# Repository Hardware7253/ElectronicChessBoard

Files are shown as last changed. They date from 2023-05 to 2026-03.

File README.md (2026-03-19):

# Electronic Chess Board
Welcome to the Electronic Chess Board project repository. This project combines an electronic chess board with a chess engine, offering a more tactile way to train against an AI opponent.

board

## Overview
The project's core objective is to deliver an interactive chess experience, allowing users to engage in matches against an AI opponent.
This AI opponent employs a minimax algorithm for strategic decision-making, with a variable search depth of 3 to 6 based on time availability. 
The chess board integrates 64 hall effect sensors to precisely detect piece positions, while the AI's moves are visually indicated using 64 LEDs.

## Code
In the [Code](/Code) directory, you'll find the firmware that powers the project. This firmware includes the chess engine responsible for AI decision-making.
The project is programmed in embedded rust, and is designed to run on the custom STM32F103C8T6 chess board.

## CAD
The [CAD](/Cad) directory contains KiCad schematics for the custom chess board PCB. Additionally, you'll find laser cutting files and 3D design files for the casing of the electronic chess board.
Manufacturing outputs for the PCB can be found in the [Manufacture](/Cad/ChessBoardKiCad/Manufacture) directory.

# Manual

## Starting the game
To begin playing, the game board will prompt you to select your team—black or white. Simply press the button while your desired team is displayed on the screen.

## Setting up the board
After starting the game, you'll be prompted to set up the chessboard. Arrange the 32 chess pieces in their starting positions, with the color that represents your team closest to you. For instance, if you are playing as the black team, ensure that the black pieces are positioned on the bottom of the board closest to you. If you need assistance during this process, you can hold down the button at any time. Doing so will illuminate LEDs on the board, indicating missing pieces or incorrectly placed ones. Once all pieces are correctly positioned, the game will automatically commence.

## Playing the game
The game follows a turn-based structure with both the user and the chess engine taking their respective turns. To make a move, simply move a chess piece and press the button to confirm that you have completed your turn. When it's the computer's turn to move, it will signal its move by blinking LEDs to indicate the destination square.

## Capturing
When capturing an opponent's piece, start by removing the captured piece from the board. Then, move your piece to its final destination and press the button to signal the end of your turn. This behavior is consistent with en passant moves, where you must first remove the captured pawn from the board before completing your move.

## Castling
To execute a castling move, move your king to its castled position without moving the rook. Press the button to indicate that you have finished your turn. After this, you may move your rook to the opposite side of the king to complete the castling maneuver.

## Errors
Errors are most likely to occur when an illegal move is made. The board's LEDs will illuminate to highlight the pieces that need adjustment to rectify the error. Additionally, the LCD screen will prompt you to revert the piece positions.

Errors may also happen when pieces are moved during the chess engine's turn. In such cases, you may notice multiple LEDs being lit up, some indicating the engine's move and others indicating pieces in the wrong position. This typically occurs when one or more pieces are slightly off-center on their squares. To resolve this issue, simply adjust the misaligned pieces inward slightly to correct the error.

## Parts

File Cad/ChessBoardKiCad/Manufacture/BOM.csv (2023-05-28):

Comment | Designator | Footprint | JLCPCB Part #
10u | C1 | Capacitor_SMD:C_0603_1608Metric | C96446
100n | C2, C3, C4, C5, C11, C14, C15, C16, C17, C18, C19, C20, C21, C22, C23, C24, C25, C26, C27, C28, C29, C30, C31, C32, C33, C34, C35, C36, C37, C38, C39, C40, C41, C42, C43, C44, C45, C46, C47, C48, C49, C50, C51, C52, C53, C54, C55, C56, C57, C58, C59, C60, C61, C62, C63, C64, C65, C66, C67, C68, C69, C70, C71, C72, C73, C74, C75, C76, C77 | Capacitor_SMD:C_0402_1005Metric | C1525
10n | C6 | Capacitor_SMD:C_0402_1005Metric | C15195
1u | C7, C8 | Capacitor_SMD:C_0402_1005Metric | C52923
22u | C9, C10 | Capacitor_SMD:C_0805_2012Metric | C45783
14p | C12, C13 | Capacitor_SMD:C_0402_1005Metric | C1548
RED | D1, D2, D3, D4, D5, D6, D7, D8, D9, D10, D11, D12, D13, D14, D15, D16, D17, D18, D19, D20, D21, D22, D23, D24, D25, D26, D27, D28, D29, D30, D31, D32, D33, D34, D35, D36, D37, D38, D39, D40, D41, D42, D43, D44, D45, D46, D47, D48, D49, D50, D51, D52, D53, D54, D55, D56, D57, D58, D59, D60, D61, D62, D63, D64, D65 | LED_SMD:LED_0603_1608Metric | C72041
WC1602A | DS1 | Display:WC1602A
120R | FB1 | Inductor_SMD:L_0603_1608Metric | C96702
MountingHole | H1, H2, H3, H4 | MountingHole:MountingHole_3.2mm_M3
USB_C_Receptacle | J1 | USB-C:USB-310D-B-SU | C309349
Conn_01x04_Pin | J2 | Connector_PinHeader_2.54mm:PinHeader_1x04_P2.54mm_Vertical
SolderJumper_2_Open | JP1 | Jumper:SolderJumper-2_P1.3mm_Open_Pad1.0x1.5mm
S9013 | Q1, Q2, Q3, Q4, Q5, Q6, Q7, Q8 | Package_TO_SOT_SMD:SOT-23 | C8512
1k5 | R1, R6, R31, R41, R51, R53, R63, R73, R83, R85 | Resistor_SMD:R_0402_1005Metric | C25867
10k | R2, R3, R32, R42, R52, R62, R72, R82, R84, R86 | Resistor_SMD:R_0402_1005Metric | C25744
5k1 | R4, R5 | Resistor_SMD:R_0402_1005Metric | C25905
2k7 | R7, R8, R9, R10, R11, R12, R13, R14, R15, R16, R17, R18, R19, R20, R21, R22, R23, R24, R25, R26, R27, R28, R29, R30, R33, R34, R35, R36, R37, R38, R39, R40, R43, R44, R45, R46, R47, R48, R49, R50, R54, R55, R56, R57, R58, R59, R60, R61, R64, R65, R66, R67, R68, R69, R70, R71, R74, R75, R76, R77, R78, R79, R80, R81 | Resistor_SMD:R_0402_1005Metric | C100347
10k | RV1 | Potentiometer_SMD:Potentiometer_Bourns_TC33X_Vertical | C515300
SW_SPST | SW1 | Button_Switch_Keyboard:SW_Cherry_MX_1.00u_PCB
AMS1117-3.3 | U1 | Package_TO_SOT_SMD:SOT-223-3_TabPin2 | C6186
STM32F103C8T6 | U2 | Package_QFP:LQFP-48_7x7mm_P0.5mm | C8734
USBLC6-2SC6 | U3 | Package_TO_SOT_SMD:SOT-23-6 | C111212
74HC595 | U4, U5, U6 | Package_SO:SOIC-16_3.9x9.9mm_P1.27mm | C5947
UHE4913G-AE3-R | U7, U8, U9, U10, U11, U12, U13, U14, U15, U16, U17, U18, U19, U20, U21, U22, U23, U24, U25, U26, U27, U28, U29, U30, U31, U32, U33, U34, U35, U36, U37, U38, U39, U40, U41, U42, U43, U44, U45, U46, U48, U49, U50, U51, U52, U53, U54, U55, U56, U57, U58, U59, U60, U61, U62, U63, U65, U66, U67, U68, U69, U70, U71, U72 | Package_TO_SOT_SMD:SOT-23W | C86815
CD4051BM | U47, U64, U73, U74, U75, U76, U77, U78, U79, U80, U81 | Package_SO:SOIC-16_3.9x9.9mm_P1.27mm | C21379
8Mhz | Y1 | Crystal:Crystal_SMD_3225-4Pin_3.2x2.5mm | C403948

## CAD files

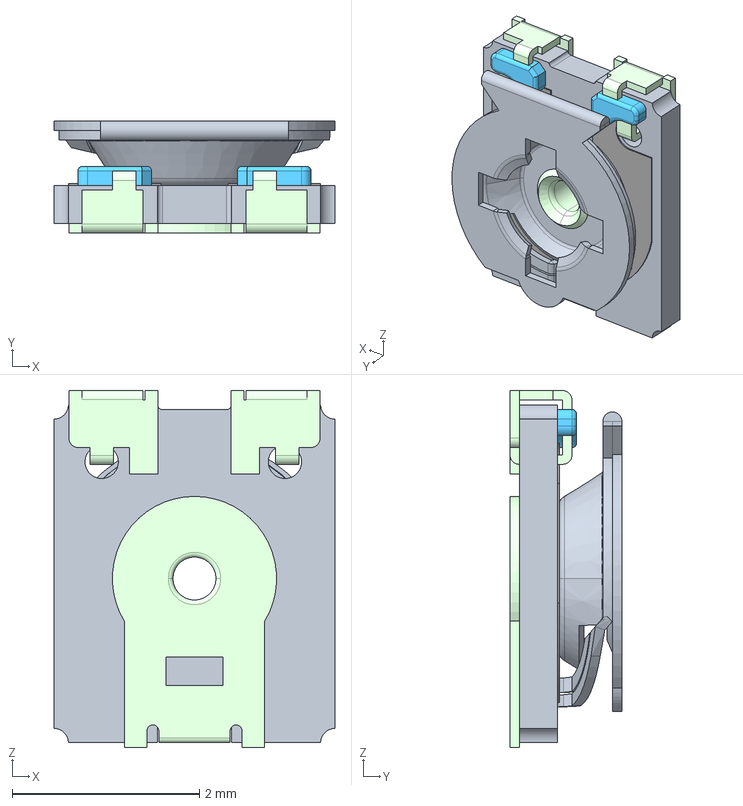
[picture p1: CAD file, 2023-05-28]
Cad/ChessBoardKiCad/3D/TC33X-1-103E.stp
3.00 x 1.19 x 3.81 mm
TC33X_SUBSTRATE
TC33X_ELEMENT
TC33X-1_COLLECTOR
TC33X_CONTACT
TC33X_TERMINALS
TC33X_SOLDER

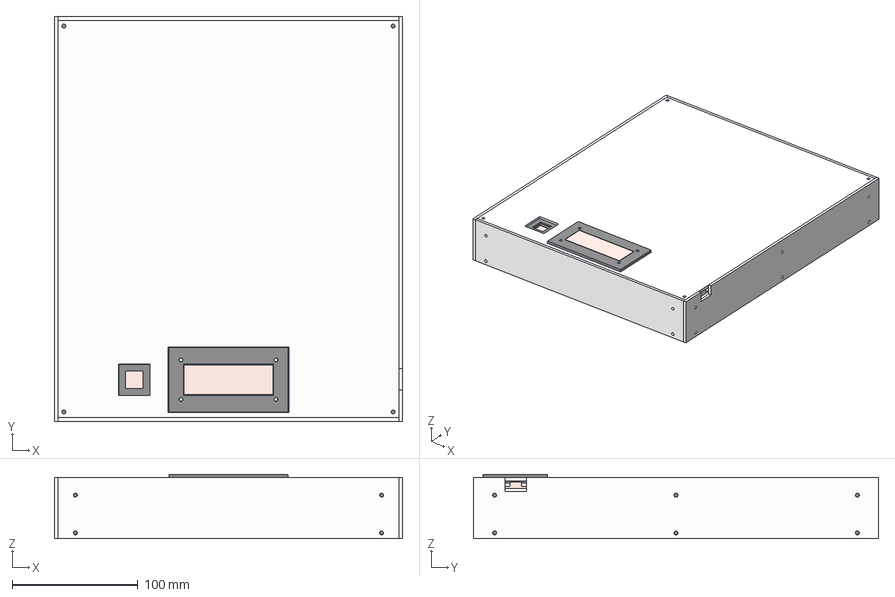
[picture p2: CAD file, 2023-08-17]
Cad/Design Files/Case.step
277.2 x 322.2 x 51.0 mm
PCB
Corner x 6
Washer x 4
PlateWasher x 4
Hardware
Panel1 x 2
Panel2
Panel3
TopPanel
Brace
SwitchPlate
ScreenCover

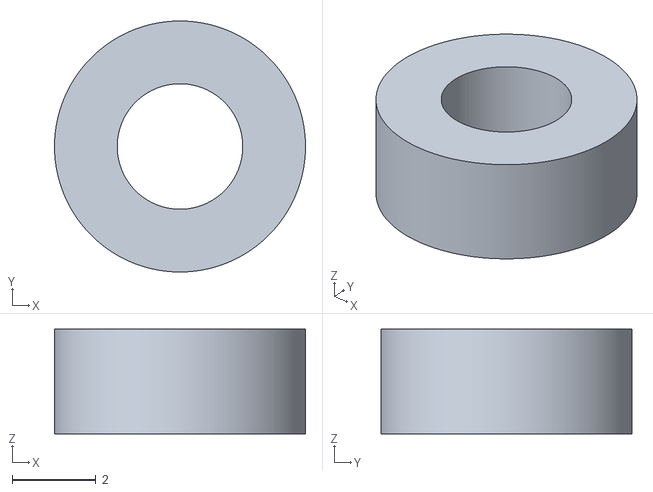
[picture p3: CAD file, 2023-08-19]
Cad/Manufacturing/ScreenSpacer.stl
6.00 x 6.00 x 2.50

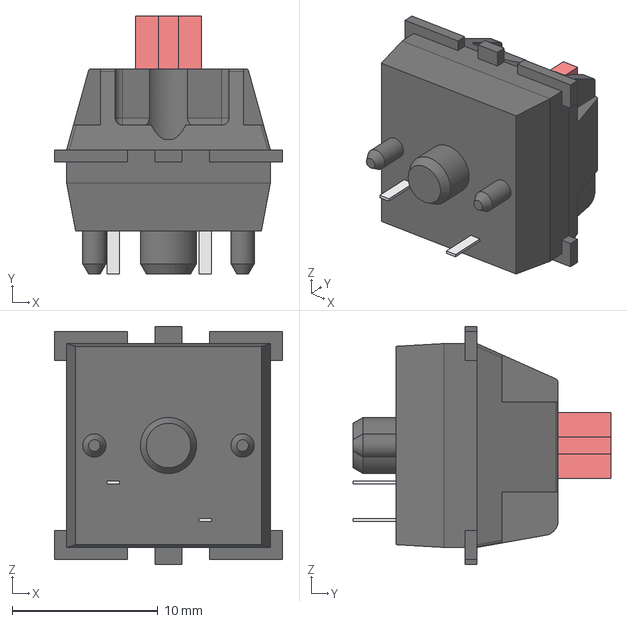
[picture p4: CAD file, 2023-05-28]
Cad/ChessBoardKiCad/3D/cherry-mx_switch.step
15.6 x 17.7 x 16.3 mm

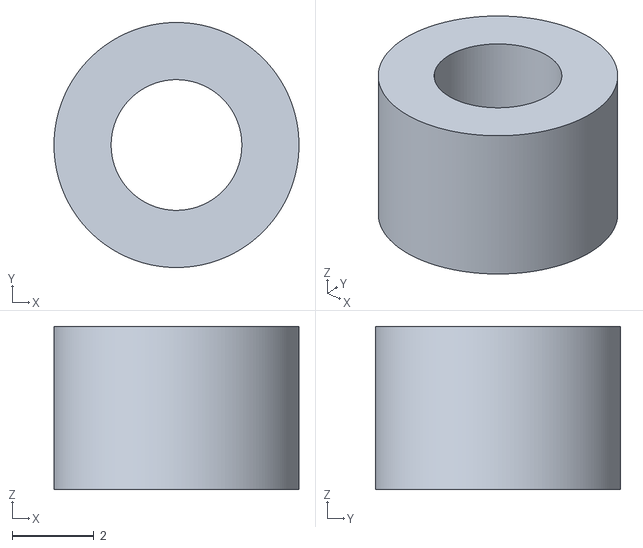
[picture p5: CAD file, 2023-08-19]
Cad/Manufacturing/PlateSpacer.stl
6.00 x 6.00 x 4.00

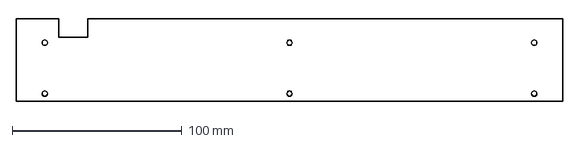
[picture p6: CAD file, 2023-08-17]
Cad/Manufacturing/LongPanelCutout.dxf
322.2 x 48.6 mm

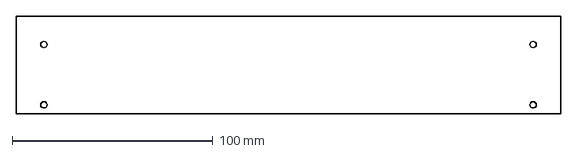
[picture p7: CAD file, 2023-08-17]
Cad/Manufacturing/ShortPanel.dxf
271.2 x 48.6 mm

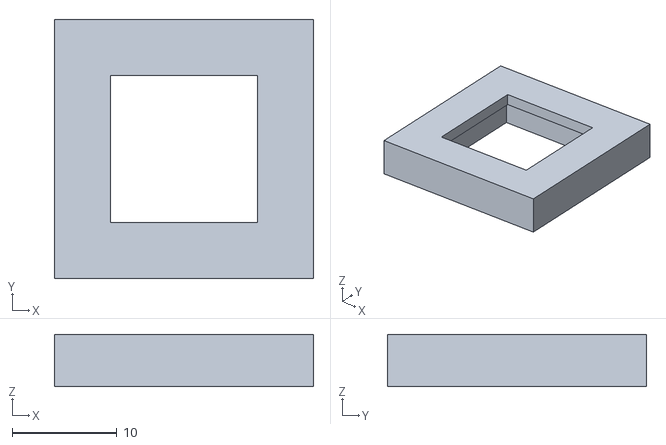
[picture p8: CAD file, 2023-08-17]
Cad/Manufacturing/SwitchPlate.stl
24.7 x 24.7 x 5.00

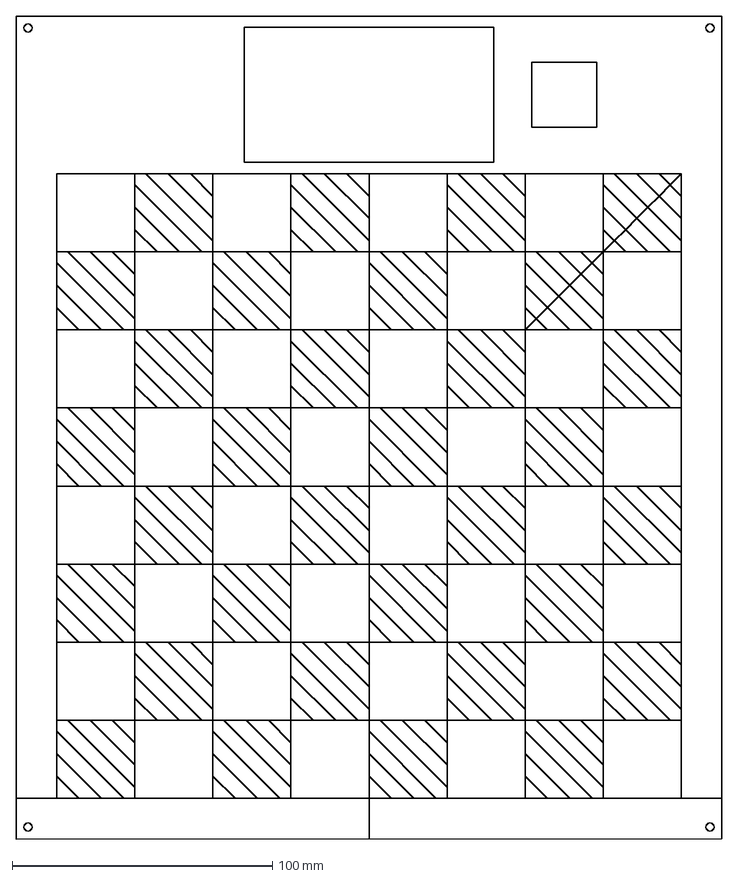
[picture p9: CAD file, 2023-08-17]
Cad/Manufacturing/TopPanel.dxf
271.2 x 316.2 mm

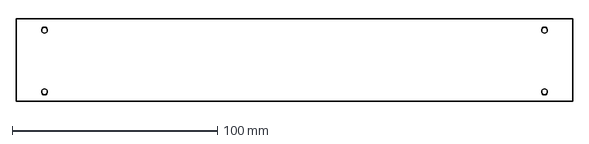
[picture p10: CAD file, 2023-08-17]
Cad/Manufacturing/Brace.dxf
271.2 x 40.0 mm

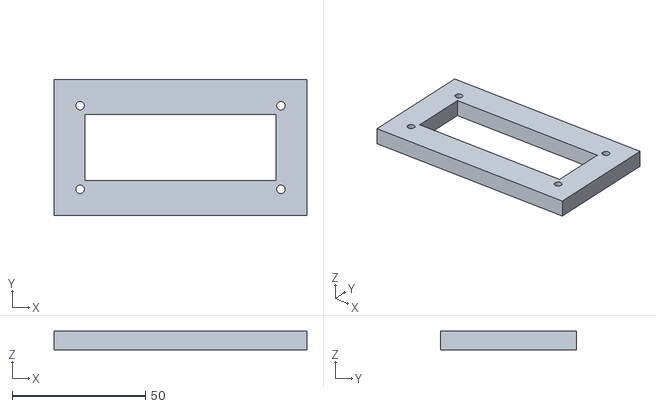
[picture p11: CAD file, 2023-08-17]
Cad/Manufacturing/ScreenCover.stl
95.0 x 51.0 x 7.00

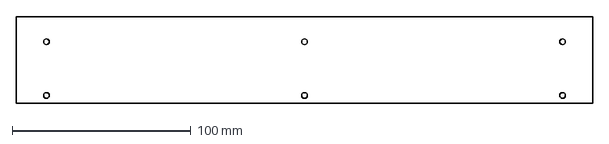
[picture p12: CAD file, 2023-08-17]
Cad/Manufacturing/LongPanel.dxf
322.2 x 48.6 mm

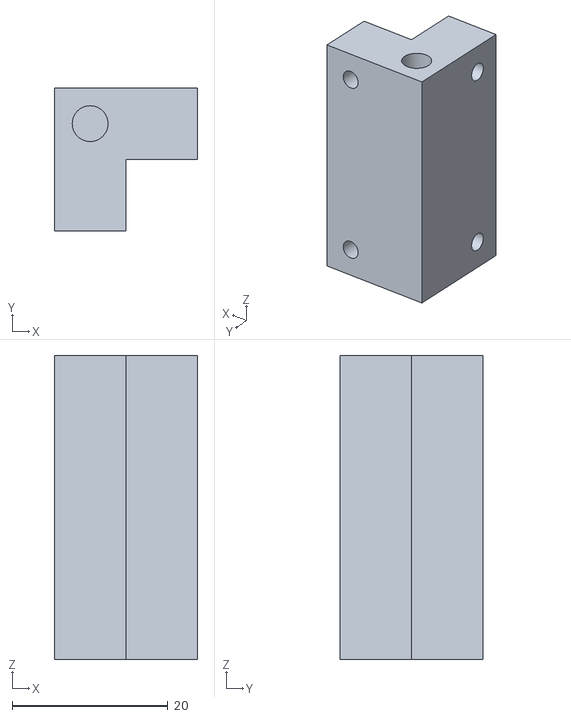
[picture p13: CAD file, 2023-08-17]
Cad/Manufacturing/Corner.stl
18.4 x 18.4 x 39.0

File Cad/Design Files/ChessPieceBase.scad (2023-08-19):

 $fa = 1;
 $fs = 0.1;
 
 // Chess magnet holder pieces
 // These pieces are glued to the bottom of normal chess pieces
 //  Recommended to be printed with a clear filament to diffuse the LED light from the PCB
 
piece_base_diameter = 20; // Diameter of the chess piece

magnet_diameter = 12; // Diameter of the magnet
magnet_height = 1; // Height of the magnet

height_from_board = 5; // Total distance to raise the attached piece from the board

difference() {
    
    // Main base piece cylinder
    cylinder( height_from_board, piece_base_diameter / 2,  piece_base_diameter / 2, false);
    
    // Magnet pocket cut cylinder
    translate([0, 0, height_from_board - magnet_height])
        cylinder(magnet_height + 0.01 , (magnet_diameter / 2), magnet_diameter / 2, false);
}
 

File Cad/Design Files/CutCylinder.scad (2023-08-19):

 $fa = 1;
 $fs = 0.1;
 
 height = 2.5; // Height of the cylinder
 internal_cylinder = 3; // Diameter of the internal cylinder (cavity)
 external_cylinder = 6; // Diamter of the external cyclinder
 
 difference() {
    cylinder( height, external_cylinder / 2, external_cylinder / 2, true);
    cylinder( height + 1, internal_cylinder / 2, internal_cylinder / 2, true);
 }
 
 

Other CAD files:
Cad/Design Files/Case.f3d

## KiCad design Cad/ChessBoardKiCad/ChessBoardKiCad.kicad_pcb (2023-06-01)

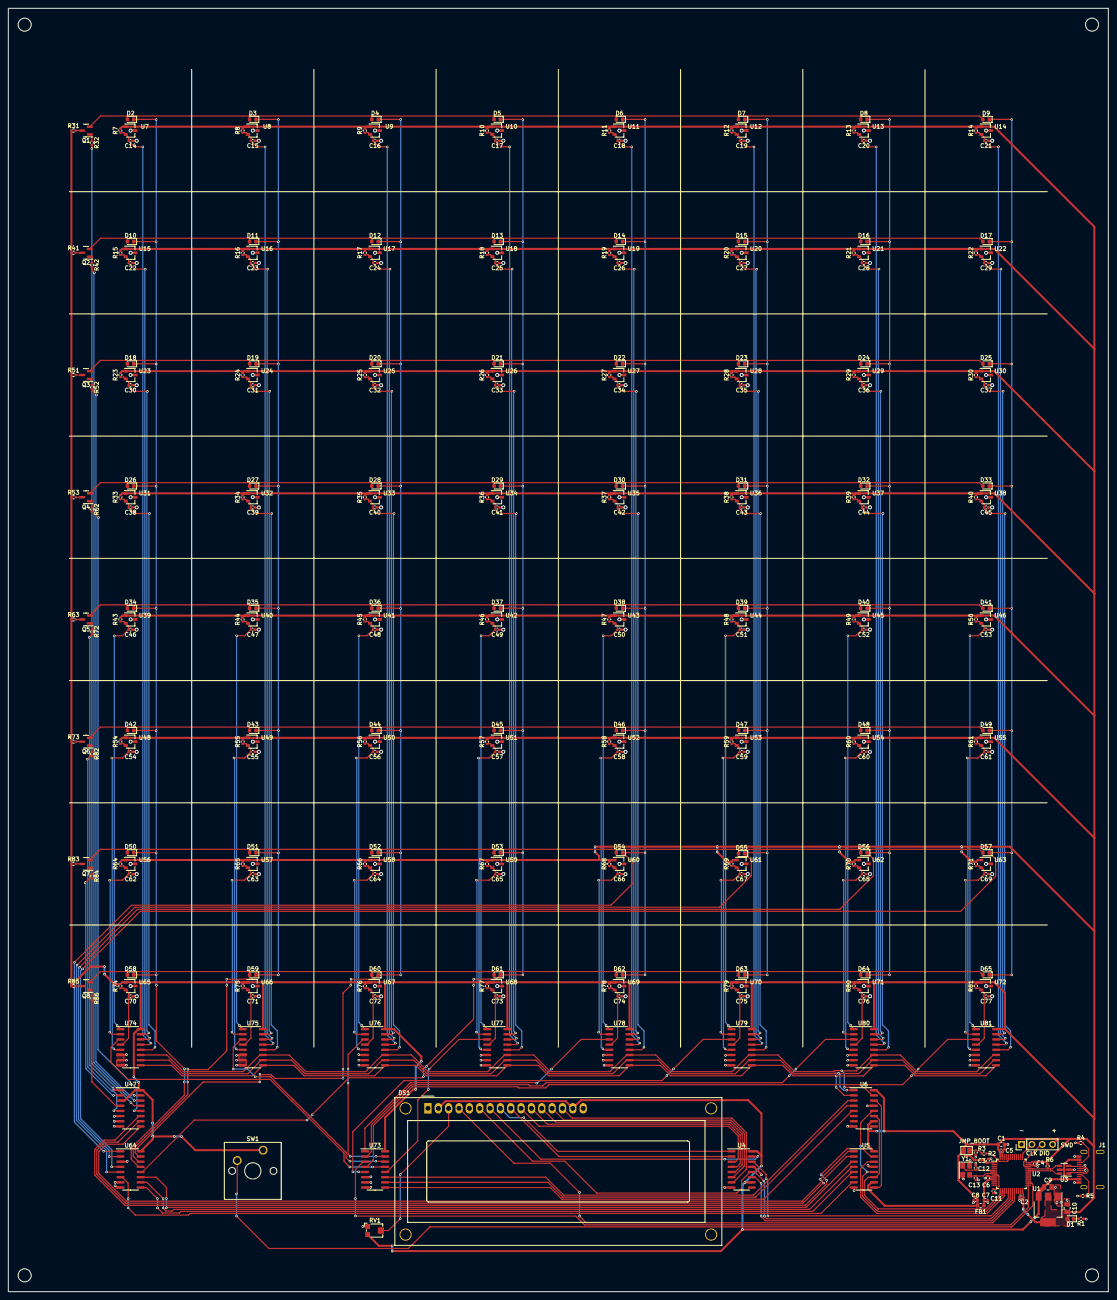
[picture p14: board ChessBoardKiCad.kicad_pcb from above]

Board: 2 copper layers, 270.0 x 315.0 mm, 329 parts (0 on the bottom side), 162 nets.

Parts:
C1: 10u; C_0603_1608Metric
C2, C3, C4, C5, C11, C14, C15, C16, C17, C18, C19, C20, C21, C22, C23, C24, C25, C26, C27, C28, C29, C30, C31, C32, C33, C34, C35, C36, C37, C38, C39, C40, C41, C42, C43, C44, C45, C46, C47, C48, C49, C50, C51, C52, C53, C54, C55, C56, C57, C58, C59, C60, C61, C62, C63, C64, C65, C66, C67, C68, C69, C70, C71, C72, C73, C74, C75, C76, C77: 100n; C_0402_1005Metric
C6: 10n; C_0402_1005Metric
C7, C8: 1u; C_0402_1005Metric
C9, C10: 22u; C_0805_2012Metric
C12, C13: 14p; C_0402_1005Metric
D1, D2, D3, D4, D5, D6, D7, D8, D9, D10, D11, D12, D13, D14, D15, D16, D17, D18, D19, D20, D21, D22, D23, D24, D25, D26, D27, D28, D29, D30, D31, D32, D33, D34, D35, D36, D37, D38, D39, D40, D41, D42, D43, D44, D45, D46, D47, D48, D49, D50, D51, D52, D53, D54, D55, D56, D57, D58, D59, D60, D61, D62, D63, D64, D65: RED; LED_0603_1608Metric
DS1: WC1602A
FB1: 120R; L_0603_1608Metric
H1, H2, H3, H4: MountingHole; MountingHole_3.2mm_M3
J1: USB_C_Receptacle; USB-310D-B-SU
J2: Conn_01x04_Pin; PinHeader_1x04_P2.54mm_Vertical
JP1: SolderJumper_2_Open; SolderJumper-2_P1.3mm_Open_Pad1.0x1.5mm
Q1, Q2, Q3, Q4, Q5, Q6, Q7, Q8: S9013; SOT-23
R1, R6, R31, R41, R51, R53, R63, R73, R83, R85: 1k5; R_0402_1005Metric
R2, R3, R32, R42, R52, R62, R72, R82, R84, R86: 10k; R_0402_1005Metric
R4, R5: 5k1; R_0402_1005Metric
R7, R8, R9, R10, R11, R12, R13, R14, R15, R16, R17, R18, R19, R20, R21, R22, R23, R24, R25, R26, R27, R28, R29, R30, R33, R34, R35, R36, R37, R38, R39, R40, R43, R44, R45, R46, R47, R48, R49, R50, R54, R55, R56, R57, R58, R59, R60, R61, R64, R65, R66, R67, R68, R69, R70, R71, R74, R75, R76, R77, R78, R79, R80, R81: 2k7; R_0402_1005Metric
RV1: 10k; Potentiometer_Bourns_TC33X_Vertical
SW1: SW_SPST; SW_Cherry_MX_1.00u_PCB
U1: AMS1117-3.3; SOT-223-3_TabPin2
U2: STM32F103C8T6; LQFP-48_7x7mm_P0.5mm
U3: USBLC6-2SC6; SOT-23-6
U4, U5, U6: 74HC595; SOIC-16_3.9x9.9mm_P1.27mm
U7, U8, U9, U10, U11, U12, U13, U14, U15, U16, U17, U18, U19, U20, U21, U22, U23, U24, U25, U26, U27, U28, U29, U30, U31, U32, U33, U34, U35, U36, U37, U38, U39, U40, U41, U42, U43, U44, U45, U46, U48, U49, U50, U51, U52, U53, U54, U55, U56, U57, U58, U59, U60, U61, U62, U63, U65, U66, U67, U68, U69, U70, U71, U72: UHE4913G-AE3-R; SOT-23W
U47, U64, U73, U74, U75, U76, U77, U78, U79, U80, U81: CD4051BM; SOIC-16_3.9x9.9mm_P1.27mm
Y1: 8Mhz; Crystal_SMD_3225-4Pin_3.2x2.5mm

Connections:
+3.3V: C1.1, C2.1, C3.1, C4.1, C5.1, C8.1, C10.1, D1.2 (A), FB1.2, J2.4, JP1.1 (A), R6.2, R7.1, R8.1, R9.1, R10.1, R11.1, R12.1, R13.1, R14.1, R15.1, R16.1, R17.1, R18.1, R19.1, R20.1, R21.1, R22.1, R23.1, R24.1, R25.1, R26.1, R27.1, R28.1, R29.1, R30.1, R31.1, R33.1, R34.1, R35.1, R36.1, R37.1, R38.1, R39.1, R40.1, R41.1, R43.1, R44.1, R45.1, R46.1, R47.1, R48.1, R49.1, R50.1, R51.1, R53.1, R54.1, R55.1, R56.1, R57.1, R58.1, R59.1, R60.1, R61.1, R63.1, R64.1, R65.1, R66.1, R67.1, R68.1, R69.1, R70.1, R71.1, R73.1, R74.1, R75.1, R76.1, R77.1, R78.1, R79.1, R80.1, R81.1, R83.1, R85.1, SW1.1 (A), U1.2 (VO), U2.1 (VBAT), U2.24 (VDD), U2.36 (VDD), U2.48 (VDD), U5.10 (~SRCLR), U5.16 (VCC), U6.10 (~SRCLR), U6.16 (VCC), U7.1 (VCC), U8.1 (VCC), U9.1 (VCC), U10.1 (VCC), U11.1 (VCC), U12.1 (VCC), U13.1 (VCC), U14.1 (VCC), U15.1 (VCC), U16.1 (VCC), U17.1 (VCC), U18.1 (VCC), U19.1 (VCC), U20.1 (VCC), U21.1 (VCC), U22.1 (VCC), U23.1 (VCC), U24.1 (VCC), U25.1 (VCC), U26.1 (VCC), U27.1 (VCC), U28.1 (VCC), U29.1 (VCC), U30.1 (VCC), U31.1 (VCC), U32.1 (VCC), U33.1 (VCC), U34.1 (VCC), U35.1 (VCC), U36.1 (VCC), U37.1 (VCC), U38.1 (VCC), U39.1 (VCC), U40.1 (VCC), U41.1 (VCC), U42.1 (VCC), U43.1 (VCC), U44.1 (VCC), U45.1 (VCC), U46.1 (VCC), U47.3 (X), U47.16 (VDD), U48.1 (VCC), U49.1 (VCC), U50.1 (VCC), U51.1 (VCC), U52.1 (VCC), U53.1 (VCC), U54.1 (VCC), U55.1 (VCC), U56.1 (VCC), U57.1 (VCC), U58.1 (VCC), U59.1 (VCC), U60.1 (VCC), U61.1 (VCC), U62.1 (VCC), U63.1 (VCC), U64.16 (VDD), U65.1 (VCC), U66.1 (VCC), U67.1 (VCC), U68.1 (VCC), U69.1 (VCC), U70.1 (VCC), U71.1 (VCC), U72.1 (VCC), U73.16 (VDD), U74.16 (VDD), U75.16 (VDD), U76.16 (VDD), U77.16 (VDD), U78.16 (VDD), U79.16 (VDD), U80.16 (VDD), U81.16 (VDD)
+3.3VA: C6.1, C7.1, FB1.1, U2.9 (VDDA)
/BOOT0: R2.1, U2.44 (BOOT0)
/CONT_1: DS1.3 (VO), RV1.2
/GRID_REGS_SER_LINK: U5.9 (QH'), U6.14 (SER)
/HSE_IN: C12.1, U2.5 (PD0), Y1.1
/HSE_OUT: C13.1, U2.6 (PD1), Y1.3
/JMP_BOOT0: JP1.2 (B), R2.2, R3.2
/LCD1_D0: DS1.7 (D0), U4.15 (QA)
/LCD1_D1: DS1.8 (D1), U4.1 (QB)
/LCD1_D2: DS1.9 (D2), U4.2 (QC)
/LCD1_D3: DS1.10 (D3), U4.3 (QD)
/LCD1_D4: DS1.11 (D4), U4.4 (QE)
/LCD1_D5: DS1.12 (D5), U4.5 (QF)
/LCD1_D6: DS1.13 (D6), U4.6 (QG)
/LCD1_D7: DS1.14 (D7), U4.7 (QH)
/NRST: C11.1, U2.7 (NRST)
/PWR_LED_K: D1.1 (K), R1.2
/R0TB: Q1.1 (B), R32.1
/R0TC: Q1.3 (C), R31.2
/R0TE: D2.2 (A), D3.2 (A), D4.2 (A), D5.2 (A), D6.2 (A), D7.2 (A), D8.2 (A), D9.2 (A), Q1.2 (E)
/R1TB: Q2.1 (B), R42.1
/R1TC: Q2.3 (C), R41.2
/R1TE: D10.2 (A), D11.2 (A), D12.2 (A), D13.2 (A), D14.2 (A), D15.2 (A), D16.2 (A), D17.2 (A), Q2.2 (E)
/R2TB: Q3.1 (B), R52.1
/R2TC: Q3.3 (C), R51.2
/R2TE: D18.2 (A), D19.2 (A), D20.2 (A), D21.2 (A), D22.2 (A), D23.2 (A), D24.2 (A), D25.2 (A), Q3.2 (E)
/R3TB: Q4.1 (B), R62.1
/R3TC: Q4.3 (C), R53.2
/R3TE: D26.2 (A), D27.2 (A), D28.2 (A), D29.2 (A), D30.2 (A), D31.2 (A), D32.2 (A), D33.2 (A), Q4.2 (E)
/R4TB: Q5.1 (B), R72.1
/R4TC: Q5.3 (C), R63.2
/R4TE: D34.2 (A), D35.2 (A), D36.2 (A), D37.2 (A), D38.2 (A), D39.2 (A), D40.2 (A), D41.2 (A), Q5.2 (E)
/R5TB: Q6.1 (B), R82.1
/R5TC: Q6.3 (C), R73.2
/R5TE: D42.2 (A), D43.2 (A), D44.2 (A), D45.2 (A), D46.2 (A), D47.2 (A), D48.2 (A), D49.2 (A), Q6.2 (E)
/R6TB: Q7.1 (B), R84.1
/R6TC: Q7.3 (C), R83.2
/R6TE: D50.2 (A), D51.2 (A), D52.2 (A), D53.2 (A), D54.2 (A), D55.2 (A), D56.2 (A), D57.2 (A), Q7.2 (E)
/R7TB: Q8.1 (B), R86.1
/R7TC: Q8.3 (C), R85.2
/R7TE: D58.2 (A), D59.2 (A), D60.2 (A), D61.2 (A), D62.2 (A), D63.2 (A), D64.2 (A), D65.2 (A), Q8.2 (E)
/SWCLK: J2.2, U2.37 (PA14)
/SWDIO: J2.3, U2.34 (PA13)
/USB_CC1: J1.A5 (CC1), R5.2
/USB_CC2: J1.B5 (CC2), R4.2
BUTTON: SW1.2 (B), U2.26 (PB13)
DISABLE_LEDS: U5.7 (QH), U64.6 (Inh)
GND: C1.2, C2.2, C3.2, C4.2, C5.2, C6.2, C7.2, C8.2, C9.2, C10.2, C11.2, C12.2, C13.2, C14.2, C15.2, C16.2, C17.2, C18.2, C19.2, C20.2, C21.2, C22.2, C23.2, C24.2, C25.2, C26.2, C27.2, C28.2, C29.2, C30.2, C31.2, C32.2, C33.2, C34.2, C35.2, C36.2, C37.2, C38.2, C39.2, C40.2, C41.2, C42.2, C43.2, C44.2, C45.2, C46.2, C47.2, C48.2, C49.2, C50.2, C51.2, C52.2, C53.2, C54.2, C55.2, C56.2, C57.2, C58.2, C59.2, C60.2, C61.2, C62.2, C63.2, C64.2, C65.2, C66.2, C67.2, C68.2, C69.2, C70.2, C71.2, C72.2, C73.2, C74.2, C75.2, C76.2, C77.2, DS1.1 (VSS), DS1.5 (R/W), DS1.16 (LED(-)), J1.A1 (GND), J1.A12 (GND), J1.B1 (GND), J1.B12 (GND), J2.1, R1.1, R3.1, R4.1, R5.1, RV1.1, U1.1 (GND), U2.8 (VSSA), U2.23 (VSS), U2.35 (VSS), U2.47 (VSS), U3.2 (GND), U4.8 (GND), U4.13 (~OE), U5.8 (GND), U5.13 (~OE), U6.8 (GND), U6.13 (~OE), U7.3 (GND), U8.3 (GND), U9.3 (GND), U10.3 (GND), U11.3 (GND), U12.3 (GND), U13.3 (GND), U14.3 (GND), U15.3 (GND), U16.3 (GND), U17.3 (GND), U18.3 (GND), U19.3 (GND), U20.3 (GND), U21.3 (GND), U22.3 (GND), U23.3 (GND), U24.3 (GND), U25.3 (GND), U26.3 (GND), U27.3 (GND), U28.3 (GND), U29.3 (GND), U30.3 (GND), U31.3 (GND), U32.3 (GND), U33.3 (GND), U34.3 (GND), U35.3 (GND), U36.3 (GND), U37.3 (GND), U38.3 (GND), U39.3 (GND), U40.3 (GND), U41.3 (GND), U42.3 (GND), U43.3 (GND), U44.3 (GND), U45.3 (GND), U46.3 (GND), U47.6 (Inh), U47.7 (VEE), U47.8 (VSS), U48.3 (GND), U49.3 (GND), U50.3 (GND), U51.3 (GND), U52.3 (GND), U53.3 (GND), U54.3 (GND), U55.3 (GND), U56.3 (GND), U57.3 (GND), U58.3 (GND), U59.3 (GND), U60.3 (GND), U61.3 (GND), U62.3 (GND), U63.3 (GND), U64.3 (X), U64.7 (VEE), U64.8 (VSS), U65.3 (GND), U66.3 (GND), U67.3 (GND), U68.3 (GND), U69.3 (GND), U70.3 (GND), U71.3 (GND), U72.3 (GND), U73.6 (Inh), U73.7 (VEE), U73.8 (VSS), U74.6 (Inh), U74.7 (VEE), U74.8 (VSS), U75.6 (Inh), U75.7 (VEE), U75.8 (VSS), U76.6 (Inh), U76.7 (VEE), U76.8 (VSS), U77.6 (Inh), U77.7 (VEE), U77.8 (VSS), U78.6 (Inh), U78.7 (VEE), U78.8 (VSS), U79.6 (Inh), U79.7 (VEE), U79.8 (VSS), U80.6 (Inh), U80.7 (VEE), U80.8 (VSS), U81.6 (Inh), U81.7 (VEE), U81.8 (VSS), Y1.2, Y1.4
GRID_LATCH: U2.14 (PA4), U5.12 (RCLK), U6.12 (RCLK)
GRID_SER_CLK: U2.13 (PA3), U5.11 (SRCLK), U6.11 (SRCLK)
GRID_SER_DATA: U2.15 (PA5), U5.14 (SER)
HALL_C0: U73.13 (X0), U74.3 (X)
HALL_C0R0: C14.1, R7.2, U7.2 (VOUT), U74.13 (X0)
HALL_C0R1: C22.1, R15.2, U15.2 (VOUT), U74.14 (X1)
HALL_C0R2: C30.1, R23.2, U23.2 (VOUT), U74.15 (X2)
HALL_C0R3: C38.1, R33.2, U31.2 (VOUT), U74.12 (X3)
HALL_C0R4: C46.1, R43.2, U39.2 (VOUT), U74.1 (X4)
HALL_C0R5: C54.1, R54.2, U48.2 (VOUT), U74.5 (X5)
HALL_C0R6: C62.1, R64.2, U56.2 (VOUT), U74.2 (X6)
HALL_C0R7: C70.1, R74.2, U65.2 (VOUT), U74.4 (X7)
HALL_C1: U73.14 (X1), U75.3 (X)
HALL_C1R0: C15.1, R8.2, U8.2 (VOUT), U75.13 (X0)
HALL_C1R1: C23.1, R16.2, U16.2 (VOUT), U75.14 (X1)
HALL_C1R2: C31.1, R24.2, U24.2 (VOUT), U75.15 (X2)
HALL_C1R3: C39.1, R34.2, U32.2 (VOUT), U75.12 (X3)
HALL_C1R4: C47.1, R44.2, U40.2 (VOUT), U75.1 (X4)
HALL_C1R5: C55.1, R55.2, U49.2 (VOUT), U75.5 (X5)
HALL_C1R6: C63.1, R65.2, U57.2 (VOUT), U75.2 (X6)
HALL_C1R7: C71.1, R75.2, U66.2 (VOUT), U75.4 (X7)
HALL_C2: U73.15 (X2), U76.3 (X)
HALL_C2R0: C16.1, R9.2, U9.2 (VOUT), U76.13 (X0)
HALL_C2R1: C24.1, R17.2, U17.2 (VOUT), U76.14 (X1)
HALL_C2R2: C32.1, R25.2, U25.2 (VOUT), U76.15 (X2)
HALL_C2R3: C40.1, R35.2, U33.2 (VOUT), U76.12 (X3)
HALL_C2R4: C48.1, R45.2, U41.2 (VOUT), U76.1 (X4)
HALL_C2R5: C56.1, R56.2, U50.2 (VOUT), U76.5 (X5)
HALL_C2R6: C64.1, R66.2, U58.2 (VOUT), U76.2 (X6)
HALL_C2R7: C72.1, R76.2, U67.2 (VOUT), U76.4 (X7)
HALL_C3: U73.12 (X3), U77.3 (X)
HALL_C3R0: C17.1, R10.2, U10.2 (VOUT), U77.13 (X0)
HALL_C3R1: C25.1, R18.2, U18.2 (VOUT), U77.14 (X1)
HALL_C3R2: C33.1, R26.2, U26.2 (VOUT), U77.15 (X2)
HALL_C3R3: C41.1, R36.2, U34.2 (VOUT), U77.12 (X3)
HALL_C3R4: C49.1, R46.2, U42.2 (VOUT), U77.1 (X4)
HALL_C3R5: C57.1, R57.2, U51.2 (VOUT), U77.5 (X5)
HALL_C3R6: C65.1, R67.2, U59.2 (VOUT), U77.2 (X6)
HALL_C3R7: C73.1, R77.2, U68.2 (VOUT), U77.4 (X7)
HALL_C4: U73.1 (X4), U78.3 (X)
HALL_C4R0: C18.1, R11.2, U11.2 (VOUT), U78.13 (X0)
HALL_C4R1: C26.1, R19.2, U19.2 (VOUT), U78.14 (X1)
HALL_C4R2: C34.1, R27.2, U27.2 (VOUT), U78.15 (X2)
HALL_C4R3: C42.1, R37.2, U35.2 (VOUT), U78.12 (X3)
HALL_C4R4: C50.1, R47.2, U43.2 (VOUT), U78.1 (X4)
HALL_C4R5: C58.1, R58.2, U52.2 (VOUT), U78.5 (X5)
HALL_C4R6: C66.1, R68.2, U60.2 (VOUT), U78.2 (X6)
HALL_C4R7: C74.1, R78.2, U69.2 (VOUT), U78.4 (X7)
HALL_C5: U73.5 (X5), U79.3 (X)
HALL_C5R0: C19.1, R12.2, U12.2 (VOUT), U79.13 (X0)
HALL_C5R1: C27.1, R20.2, U20.2 (VOUT), U79.14 (X1)
HALL_C5R2: C35.1, R28.2, U28.2 (VOUT), U79.15 (X2)
HALL_C5R3: C43.1, R38.2, U36.2 (VOUT), U79.12 (X3)
HALL_C5R4: C51.1, R48.2, U44.2 (VOUT), U79.1 (X4)
HALL_C5R5: C59.1, R59.2, U53.2 (VOUT), U79.5 (X5)
HALL_C5R6: C67.1, R69.2, U61.2 (VOUT), U79.2 (X6)
HALL_C5R7: C75.1, R79.2, U70.2 (VOUT), U79.4 (X7)
HALL_C6: U73.2 (X6), U80.3 (X)
HALL_C6R0: C20.1, R13.2, U13.2 (VOUT), U80.13 (X0)
HALL_C6R1: C28.1, R21.2, U21.2 (VOUT), U80.14 (X1)
HALL_C6R2: C36.1, R29.2, U29.2 (VOUT), U80.15 (X2)
HALL_C6R3: C44.1, R39.2, U37.2 (VOUT), U80.12 (X3)
HALL_C6R4: C52.1, R49.2, U45.2 (VOUT), U80.1 (X4)
HALL_C6R5: C60.1, R60.2, U54.2 (VOUT), U80.5 (X5)
HALL_C6R6: C68.1, R70.2, U62.2 (VOUT), U80.2 (X6)
HALL_C6R7: C76.1, R80.2, U71.2 (VOUT), U80.4 (X7)
HALL_C7: U73.4 (X7), U81.3 (X)
HALL_C7R0: C21.1, R14.2, U14.2 (VOUT), U81.13 (X0)
HALL_C7R1: C29.1, R22.2, U22.2 (VOUT), U81.14 (X1)
HALL_C7R2: C37.1, R30.2, U30.2 (VOUT), U81.15 (X2)
HALL_C7R3: C45.1, R40.2, U38.2 (VOUT), U81.12 (X3)
HALL_C7R4: C53.1, R50.2, U46.2 (VOUT), U81.1 (X4)
HALL_C7R5: C61.1, R61.2, U55.2 (VOUT), U81.5 (X5)
HALL_C7R6: C69.1, R71.2, U63.2 (VOUT), U81.2 (X6)
HALL_C7R7: C77.1, R81.2, U72.2 (VOUT), U81.4 (X7)
HALL_COL_A: U6.3 (QD), U73.11 (A)
HALL_COL_B: U6.4 (QE), U73.10 (B)
HALL_COL_C: U6.5 (QF), U73.9 (C)
HALL_ROW_A: U6.15 (QA), U74.11 (A), U75.11 (A), U76.11 (A), U77.11 (A), U78.11 (A), U79.11 (A), U80.11 (A), U81.11 (A)
HALL_ROW_B: U6.1 (QB), U74.10 (B), U75.10 (B), U76.10 (B), U77.10 (B), U78.10 (B), U79.10 (B), U80.10 (B), U81.10 (B)
HALL_ROW_C: U6.2 (QC), U74.9 (C), U75.9 (C), U76.9 (C), U77.9 (C), U78.9 (C), U79.9 (C), U80.9 (C), U81.9 (C)
LCD_LATCH: DS1.6 (E), U2.18 (PB0), U4.12 (RCLK)
LCD_RS: DS1.4 (RS), U2.20 (PB2)
LCD_SER_CLK: U2.19 (PB1), U4.11 (SRCLK)
LCD_SER_DATA: U2.17 (PA7), U4.14 (SER)
LED_C0: D2.1 (K), D10.1 (K), D18.1 (K), D26.1 (K), D34.1 (K), D42.1 (K), D50.1 (K), D58.1 (K), U64.13 (X0)
LED_C1: D3.1 (K), D11.1 (K), D19.1 (K), D27.1 (K), D35.1 (K), D43.1 (K), D51.1 (K), D59.1 (K), U64.14 (X1)
LED_C2: D4.1 (K), D12.1 (K), D20.1 (K), D28.1 (K), D36.1 (K), D44.1 (K), D52.1 (K), D60.1 (K), U64.15 (X2)
LED_C3: D5.1 (K), D13.1 (K), D21.1 (K), D29.1 (K), D37.1 (K), D45.1 (K), D53.1 (K), D61.1 (K), U64.12 (X3)
LED_C4: D6.1 (K), D14.1 (K), D22.1 (K), D30.1 (K), D38.1 (K), D46.1 (K), D54.1 (K), D62.1 (K), U64.1 (X4)
LED_C5: D7.1 (K), D15.1 (K), D23.1 (K), D31.1 (K), D39.1 (K), D47.1 (K), D55.1 (K), D63.1 (K), U64.5 (X5)
LED_C6: D8.1 (K), D16.1 (K), D24.1 (K), D32.1 (K), D40.1 (K), D48.1 (K), D56.1 (K), D64.1 (K), U64.2 (X6)
LED_C7: D9.1 (K), D17.1 (K), D25.1 (K), D33.1 (K), D41.1 (K), D49.1 (K), D57.1 (K), D65.1 (K), U64.4 (X7)
LED_COL_A: U5.3 (QD), U64.11 (A)
LED_COL_B: U5.4 (QE), U64.10 (B)
LED_COL_C: U5.5 (QF), U64.9 (C)
LED_R0: R32.2, U47.13 (X0)
LED_R1: R42.2, U47.14 (X1)
LED_R2: R52.2, U47.15 (X2)
LED_R3: R62.2, U47.12 (X3)
LED_R4: R72.2, U47.1 (X4)
LED_R5: R82.2, U47.5 (X5)
LED_R6: R84.2, U47.2 (X6)
LED_R7: R86.2, U47.4 (X7)
LED_ROW_A: U5.15 (QA), U47.11 (A)
LED_ROW_B: U5.1 (QB), U47.10 (B)
LED_ROW_C: U5.2 (QC), U47.9 (C)
SELECTED_HALL: U2.25 (PB12), U73.3 (X)
USB_CON_D+: J1.A6 (D+), J1.B6 (D+), U3.3 (I/O2)
USB_CON_D-: J1.A7 (D-), J1.B7 (D-), U3.1 (I/O1)
USB_D+: R6.1, U2.33 (PA12), U3.4 (I/O2)
USB_D-: U2.32 (PA11), U3.6 (I/O1)
VBUS: C9.1, DS1.2 (VDD), DS1.15 (LED(+)), J1.A4 (VBUS), J1.A9 (VBUS), J1.B4 (VBUS), J1.B9 (VBUS), RV1.3, U1.3 (VI), U3.5 (VBUS), U4.10 (~SRCLR), U4.16 (VCC)

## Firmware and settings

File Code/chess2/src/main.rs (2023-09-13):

#![no_std]
#![no_main]

use panic_halt as _;

use cortex_m_rt::entry;
use embedded_hal::digital::v2::InputPin;
use stm32f1xx_hal as hal;
use hal::{pac, delay::Delay, prelude::*};

use arrform::{arrform, ArrForm};

use rtt_target::{rprintln, rtt_init_print};


use chess2::board::board_representation;
use chess2::algorithm;
use chess2::embedded;

#[entry]
fn main() -> ! {
    // Init buffers for debug printing
    rtt_init_print!();

    // Get access to device and core peripherals
    let dp = pac::Peripherals::take().unwrap();
    let mut cp = cortex_m::Peripherals::take().unwrap();

    // Get access to RCC, FLASH, AFIO, and GPIO
    let mut rcc = dp.RCC.constrain();
    let mut flash = dp.FLASH.constrain();
    //let mut afio = dp.AFIO.constrain(&mut rcc.apb2);
    let mut gpioa = dp.GPIOA.split(&mut rcc.apb2);
    let mut gpiob = dp.GPIOB.split(&mut rcc.apb2);

    // Configure and apply clock configuration
    let clock_mhz = 72;
    let clocks = rcc.cfgr
        // External oscillator
        .use_hse(8.mhz())

        // Bus and core clocks
        .hclk(clock_mhz.mhz())
        .sysclk(clock_mhz.mhz())

        // Peripheral clocks
        .pclk1(12.mhz())
        .pclk2(12.mhz())
    .freeze(&mut flash.acr);

    // Set up systick delay
    let mut delay = Delay::new(cp.SYST, clocks);

    // Enable cycle counter
    cp.DCB.enable_trace();
    cp.DWT.enable_cycle_counter();

    let mut cycle_counter = embedded::cycle_counter::Counter::new();

    // Initialise hall and led grid shift register
    let mut grid_sr = embedded::ShiftRegister {
        clock: gpioa.pa3.into_push_pull_output(&mut gpioa.crl).downgrade(),
        data: gpioa.pa5.into_push_pull_output(&mut gpioa.crl).downgrade(),
        latch: gpioa.pa4.into_push_pull_output(&mut gpioa.crl).downgrade(),
        bits: 16,
    };
    grid_sr.init(&mut delay);
    embedded::write_grid(&mut grid_sr, &mut delay, 0, false); // Initialise grid with leds off

    // Initialise character lcd
    let mut lcd = embedded::character_lcd::Lcd {
        shift_register: embedded::ShiftRegister {
            clock: gpiob.pb1.into_push_pull_output(&mut gpiob.crl).downgrade(),
            data: gpioa.pa7.into_push_pull_output(&mut gpioa.crl).downgrade(),
            latch: gpiob.pb0.into_push_pull_output(&mut gpiob.crl).downgrade(),
            bits: 8,
        },
        register_select: gpiob.pb2.into_push_pull_output(&mut gpiob.crl).downgrade(),
    };
    lcd.init(&mut delay);

    let hall_sensor = gpiob.pb12.into_floating_input(&mut gpiob.crh).downgrade(); // Pin to read value of the selected hall sensor

    let mut button = embedded::button::Button {
        pin: gpiob.pb13.into_pull_down_input(&mut gpiob.crh).downgrade(),
        press_raw: false,
        press_start_cycle: None,
        long_press_cycles: embedded::ms_to_cycles(650, clock_mhz as u64), // Button needs to be held for atleast 650ms for a long press
        long_press: false,
        last_press_cycle: 0,
        debounce_cycles: embedded::ms_to_cycles(50, clock_mhz as u64), // 50ms debounce
        consecutive_cycles: embedded::ms_to_cycles(150, clock_mhz as u64), // When button presses are registered less than 160ms apart then the presses are sequential
        c_presses: 0,
        consecutive_presses: 0, 
    };

    // Initiliaze board to starting board
    let starting_board = board_representation::Board {
        board: [71776119061217280, 9295429630892703744, 4755801206503243776, 2594073385365405696, 576460752303423488, 1152921504606846976, 65280, 129, 66, 36, 8, 16, 7926616819148718190],
        whites_move: true,
        points: board_representation::Points { white_points: 0, black_points: 0 },
        points_delta: 0,
        half_moves: 0,
        half_move_clock: 0,
        en_passant_target: None
    };

    let pieces_info = chess2::piece::constants::gen(); // Generate piece info

    let led_strobe_us: u32 = 200000; // Led strobe time (on time) in micro seconds

    let max_search_times: [u64; 8] = [1000, 3000, 5000, 10000, 20000, 30000, 50000, 100000]; // Options for maximum search times (ms) for the minimax algorithm
    let mut search_time_index: usize = 2; // Index for the currently selected minimax search time
    let max_search_depth = 6; // Maximum minimax search depth

    let mut opening_heatmap = [[0i16; 64]; 12];
    // Testing how many clock cycles it takes for the computer the generate a move from a starting board position at a search depth of 4
    /*
    cycle_counter.update();
    let start_cycles = cycle_counter.cycles;

    algorithm::gen_best_move(
        true,
        &mut cycle_counter,
        &start_cycles,
        &chess2::embedded::ms_to_cycles(100000, clock_mhz as u64),
        4,
        0,
        0,
        algorithm::AlphaBeta::new(),
        &opening_heatmap,
        starting_board,
        &pieces_info,
    );

    cycle_counter.update();
    let end_cycles = cycle_counter.cycles;
    let elapsed_cycles = end_cycles - start_cycles;

    rprintln!("Computer move took {} clock cycles", elapsed_cycles);
    rprintln!("(Rougly {} seconds)", elapsed_cycles / (clock_mhz as u64 * 1000000));
    */

    loop {
        delay.delay_ms(1u16);
        lcd.clear(&mut delay);
        opening_heatmap = [[0, 0, 0, 0, 0, 0, 0, 0, 0, 0, 0, 0, 0, 0, 2, 0, 10, 1, 18, 10, 9, 9, 1, 0, 1, 33, 61, 475, 338, 22, 6, 5, 51, 142, 1144, 2288, 2246, 392, 88, 80, 88, 74, 361, 111, 276, 124, 322, 62, 0, 0, 0, 0, 0, 0, 0, 0, 0, 0, 0, 0, 0, 0, 0, 0], [0, 0, 0, 0, 0, 0, 0, 1, 0, 0, 0, 0, 0, 0, 0, 0, 0, 0, 0, 0, 0, 0, 0, 0, 0, 0, 0, 0, 7, 0, 0, 0, 0, 0, 0, 0, 3, 0, 0, 0, 1, 0, 4, 0, 1, 0, 0, 1, 0, 0, 0, 0, 0, 0, 0, 0, 0, 5, 35, 32, 94, 499, 3, 0], [1, 0, 0, 0, 0, 0, 0, 2, 0, 0, 2, 0, 0, 19, 0, 2, 0, 0, 15, 1, 2, 7, 0, 0, 1, 31, 0, 19, 145, 2, 79, 0, 9, 0, 11, 268, 58, 0, 1, 7, 16, 17, 1470, 1, 3, 2054, 9, 15, 0, 0, 2, 115, 62, 1, 0, 0, 0, 1, 0, 0, 5, 2, 2, 0], [1, 0, 0, 0, 0, 0, 0, 0, 0, 1, 1, 3, 20, 22, 1, 0, 0, 1, 35, 0, 0, 17, 0, 2, 0, 314, 1, 13, 2, 0, 292, 0, 139, 2, 509, 2, 0, 47, 0, 35, 6, 108, 1, 162, 124, 1, 2, 3, 0, 51, 19, 57, 148, 1, 205, 0, 1, 0, 2, 0, 0, 3, 0, 0], [0, 0, 0, 2, 0, 0, 0, 1, 0, 0, 0, 0, 0, 1, 3, 2, 0, 0, 0, 0, 0, 0, 0, 1, 0, 1, 1, 4, 1, 2, 0, 24, 22, 0, 13, 32, 3, 2, 24, 3, 0, 48, 7, 17, 6, 42, 0, 0, 0, 0, 66, 49, 67, 3, 0, 0, 0, 1, 0, 3, 3, 0, 0, 0], [0, 0, 0, 0, 0, 0, 0, 0, 0, 0, 0, 0, 0, 0, 0, 0, 0, 0, 0, 0, 0, 0, 0, 0, 0, 0, 0, 0, 0, 0, 0, 0, 0, 0, 0, 0, 0, 0, 0, 0, 0, 0, 0, 0, 1, 0, 1, 0, 0, 0, 0, 0, 9, 4, 1, 0, 0, 0, 23, 4, 0, 26, 498, 6], [0, 0, 0, 0, 0, 0, 0, 0, 0, 0, 0, 0, 0, 0, 0, 0, 348, 125, 418, 716, 867, 40, 525, 86, 17, 238, 834, 1360, 1326, 216, 134, 18, 0, 13, 174, 512, 190, 170, 68, 4, 1, 0, 34, 3, 4, 37, 4, 0, 0, 6, 0, 0, 0, 0, 0, 2, 0, 0, 0, 0, 0, 0, 0, 0], [0, 8, 3, 3, 17, 458, 5, 0, 1, 0, 0, 0, 0, 1, 0, 1, 0, 0, 0, 0, 1, 0, 0, 0, 0, 0, 0, 0, 0, 0, 0, 0, 0, 0, 0, 0, 0, 0, 0, 0, 0, 0, 0, 0, 0, 0, 0, 0, 0, 0, 0, 0, 0, 0, 0, 0, 1, 0, 0, 0, 0, 0, 0, 0], [0, 13, 0, 2, 1, 1, 8, 0, 0, 4, 3, 219, 58, 2, 1, 0, 21, 32, 1057, 15, 1, 1874, 4, 29, 56, 0, 8, 130, 31, 3, 1, 10, 0, 9, 4, 40, 190, 2, 21, 0, 0, 0, 31, 0, 2, 1, 3, 0, 0, 0, 1, 2, 0, 2, 0, 0, 0, 0, 0, 0, 0, 2, 0, 0], [0, 0, 0, 0, 1, 3, 0, 1, 1, 74, 0, 44, 307, 0, 387, 2, 20, 31, 2, 44, 56, 5, 9, 5, 27, 0, 241, 0, 2, 79, 3, 1, 0, 297, 3, 5, 2, 0, 98, 4, 0, 0, 60, 3, 1, 8, 0, 3, 0, 0, 0, 5, 1, 3, 1, 1, 0, 1, 0, 1, 0, 3, 0, 0], [1, 1, 2, 4, 5, 0, 0, 0, 0, 0, 36, 10, 62, 0, 0, 0, 0, 28, 0, 10, 2, 36, 6, 0, 79, 0, 0, 53, 5, 4, 12, 2, 0, 1, 1, 9, 3, 2, 0, 51, 1, 0, 1, 0, 0, 0, 0, 2, 0, 2, 0, 0, 0, 0, 3, 0, 0, 0, 0, 0, 0, 0, 0, 0], [0, 0, 2, 7, 0, 4, 458, 0, 0, 0, 0, 0, 5, 17, 2, 0, 0, 0, 0, 0, 1, 1, 0, 0, 0, 0, 0, 0, 0, 0, 0, 0, 0, 0, 0, 0, 0, 0, 0, 0, 0, 0, 0, 0, 0, 0, 0, 0, 0, 0, 0, 0, 0, 0, 0, 0, 0, 0, 0, 0, 0, 0, 0, 0]];

        // Get player team
        let mut player_white = true;
        {
            let mut game_started = false;
            

            let mut team_message_start_cycle = 0; // The clock cycle the current team select message started getting displayed at
            let team_message_cycles = embedded::ms_to_cycles(1000, clock_mhz as u64); // How many clock cycles the game start message should be displayed for before switching to the oposite team

            while !game_started {

                // Display start game message for white and black
                lcd.set_cursor(&mut delay, [0, 0]);
                if player_white {
                    lcd.print(&mut delay, "Start as white?");
                } else {
                    lcd.print(&mut delay, "Start as black?");                
                }
                lcd.set_cursor(&mut delay, [0, 1]);
                lcd.print(&mut delay, "(Press button)");


                if button.press(&mut cycle_counter) {
                    game_started = true;
                }

                if cycle_counter.cycles > team_message_start_cycle + team_message_cycles {
                    team_message_start_cycle = cycle_counter.cycles;
                    player_white = !player_white;
                }
            }
        }

        lcd.clear(&mut delay);

        // Ensure the physical board is set up properly
        let mut physical_bitboard = embedded::read_board_halls(&mut grid_sr, &hall_sensor, &mut delay); // Get bitboard of pieces on the physical board
        {
            let expected_board: u64 = 0b1111111111111111000000000000000000000000000000001111111111111111;
            
            while physical_bitboard != expected_board {
                lcd.set_cursor(&mut delay, [0, 0]);
                lcd.print(&mut delay, "Please setup");
                lcd.set_cursor(&mut delay, [0, 1]);
                lcd.print(&mut delay, "the board");

                physical_bitboard = embedded::read_board_halls(&mut grid_sr, &hall_sensor, &mut delay); // Update physical bitboard

                // If the button is pressed highlight the positions where pieces have to placed
                button.press(&mut cycle_counter);
                if button.press_raw {
                    embedded::leds_from_bitboard(&mut grid_sr, &mut delay, expected_board ^ physical_bitboard, led_strobe_us, true);
                }

                delay.delay_ms(1u16);
            }
        }

        // Initialise board
        let mut board = starting_board;

        // Game loop
        // Each loop represents one turn
        // The loop will break once the game has finished
        'game: loop {
            lcd.clear(&mut delay);

            let players_turn = player_white == board.whites_move; // Determine wether the current turn is for the player or computer to make

            // Piece move for the chess engine and the physical board must be stored seperately
            // Because the physical board has a dynamic orientation for the teams, while the internal engine board representation has a static orientation for the white and black team perspective
            let mut piece_internal_move = algorithm::Move::new();
            let mut piece_physical_move = algorithm::Move::new();

            physical_bitboard = embedded::read_board_halls(&mut grid_sr, &hall_sensor, &mut delay); // Get bitboard of pieces on the physical board before a piece has been moved

            // Get move from player / computer
            if players_turn {

                let mut init_physical_bitboard = physical_bitboard;

                // Loop until the player has made a proper move
                let mut piece_removed = false;
                loop {
                    lcd.set_cursor(&mut delay, [0, 0]);
                    lcd.print(&mut delay, "Players turn");
                    lcd.set_cursor(&mut delay, [0, 1]);
                    lcd.print(&mut delay, "(");
                    lcd_print_team(&mut lcd, &mut delay, player_white);
                    lcd.print(&mut delay, ")");

                    let new_physical_bitboard = embedded::read_board_halls(&mut grid_sr, &hall_sensor, &mut delay); // Get bitboard of pieces on the physical board

                    let piece_change = chess2::find_piece_change(physical_bitboard, new_physical_bitboard);

                    // Keep track of pieces being removed from the board so pieces can be captured without throwing an error
                    if piece_change == -1 {
                        if !piece_removed {
                            // Set the initial bitboard to the current bitboard if one piece is removed from the board
                            // This allows the capture move to be detected
                            // Only the first piece that is removed from the board can be captured
                            init_physical_bitboard = new_physical_bitboard;
                            piece_removed = true;
                        }
                    } else if piece_change > -1 {
                        init_physical_bitboard = physical_bitboard;
                    }

                    let button_pressed = button.press(&mut cycle_counter);

                    // When the button registers a long press open a menu to change the maximum time that the computer takes to search
                    if button.long_press {
                        lcd.clear(&mut delay);

                        let mut increment_queued = false;
                        let mut press_start_cycle: Option<u64> = None;
                        loop {
                            lcd.set_cursor(&mut delay, [0, 0]);
                            lcd.print(&mut delay, "Engine search");
                            lcd.set_cursor(&mut delay, [0, 1]);
                    
                            let af = arrform!(64, "{}s", max_search_times[search_time_index] / 1000);
                            lcd.print(&mut delay, af.as_str());

                            let button_pressed = button.press(&mut cycle_counter);

                            // Long press the button again to close the menu
                            if button.long_press {
                                break;
                            }

                            // If the button is pressed increment the search_time_index
                            if button_pressed {
                                increment_queued = true;
                                press_start_cycle = button.press_start_cycle;
                            }

                            // Queue increment of the search time until after the button has been released
                            // This avoids the value updating while the user is trying to long press to exit the menu
                            if increment_queued && press_start_cycle != button.press_start_cycle {
                                lcd.clear(&mut delay);
                                search_time_index += 1;
                                if search_time_index > (max_search_times.len() - 1) {
                                    search_time_index = 0;
                                }
                                increment_queued = false;
                            }
                        }
                        button.consecutive_presses = 0; // Reset consecutive presses that may have been made while the user cycles through the search times
                        lcd.clear(&mut delay);
                    }

                    // When the button is pressed greater than 9 times consecutevily resign
                    if button.consecutive_presses > 9 {
                        break 'game;
                    }

                    if button_pressed {

                        // Do nothing if the board has not changed
                        if physical_bitboard == new_physical_bitboard {
                            continue;
                        }
                        
                        let player_move = chess2::find_bitboard_move(init_physical_bitboard, new_physical_bitboard, &board, player_white);

                        button.press(&mut cycle_counter);

                        match player_move {

                            // If the move was ok break the loop
                            Ok(player_move) => {
                                piece_physical_move = player_move;
                                break;
                            },

                            // If there was an error with the move make the player revert the move so they can try again
                            Err(pieces_moved) => {
                                lcd.clear(&mut delay);
                                lcd.set_cursor(&mut delay, [0, 0]);
                                lcd.print(&mut delay, "Invalid move");
                                lcd.set_cursor(&mut delay, [0, 1]);
                                lcd.print(&mut delay, "Please revert");

                                show_bitboard_move(physical_bitboard, &mut grid_sr, &hall_sensor, led_strobe_us, &mut delay);
                                lcd.clear(&mut delay);
                                piece_removed = false;
                                button.press(&mut cycle_counter);
                            },
                        }                        
                    }
                }
            } else {
                lcd.set_cursor(&mut delay, [0, 0]);
                lcd.print(&mut delay, "Computers turn");
                lcd.set_cursor(&mut delay, [0, 1]);
                lcd.print(&mut delay, "(");
                lcd_print_team(&mut lcd, &mut delay, !player_white);
                lcd.print(&mut delay, ")");

                cycle_counter.update();
                let start_cycles = cycle_counter.cycles;

                // Generate a move which takes no longer than max_search_times[search_time_index] and has a maximum search depth of max_search_depth
                piece_internal_move = algorithm::gen_best_move(
                    true,
                    &mut cycle_counter,
                    &start_cycles,
                    &chess2::embedded::ms_to_cycles(max_search_times[search_time_index], clock_mhz as u64),
                    max_search_depth,
                    0,
                    0,
                    algorithm::AlphaBeta::new(),
                    &opening_heatmap,
                    board,
                    &pieces_info,
                ).piece_move.unwrap();
            }

            // Set piece_internal / piece_physical move (whichever hasn't been updated yet)
            if player_white {

                // When the player is white the physical and internal boards are the same orientation so nothing needs to be flipped
                if players_turn {
                    piece_internal_move = piece_physical_move;
                } else {
                    piece_physical_move = piece_internal_move;
                }
            } else {

                // When the player is black the physical and internal boards are opposite orientations so the moves have to flipped
                if players_turn {
                    piece_internal_move = piece_physical_move.flip();
                    piece_internal_move.initial_piece_coordinates.board_index = chess2::find_board_index(&board, piece_internal_move.initial_piece_coordinates.bit).unwrap(); // Update board index
                } else {
                    piece_physical_move = piece_internal_move.flip();
                } 
            }

            // Get friendly and enemy kings
            let friendly_king_index;
            let enemy_king_index;
            if board.whites_move {
                friendly_king_index = 5;
                enemy_king_index = 11;
            } else {
                friendly_king_index = 11;
                enemy_king_index = 5;
            }

            let friendly_king = board_representation::BoardCoordinates {
                board_index: friendly_king_index,
                bit: chess2::find_bit_on(board.board[friendly_king_index], 0),
            };

            let enemy_king = board_representation::BoardCoordinates {
                board_index: enemy_king_index,
                bit: chess2::find_bit_on(board.board[enemy_king_index], 0),
            };

            use chess2::board::move_generator;
            use move_generator::TurnError;

            // Get new board after turn has been made
            let team_bitboards = chess2::TeamBitboards::new(friendly_king.board_index, &board);
            let enemy_attacks = move_generator::gen_enemy_attacks(&friendly_king, team_bitboards, &board, &pieces_info);
            let new_turn_board = move_generator::new_turn(&piece_internal_move.initial_piece_coordinates, piece_internal_move.final_piece_bit, friendly_king, &enemy_king, &enemy_attacks, team_bitboards, board, &pieces_info);

            match new_turn_board {
                Ok(new_board) => {

                    // Get what the phsysical bitboard should be after the turn is made
                    let mut new_physical_bitboard = new_board.to_bitboard();

                    if !player_white {
                        new_physical_bitboard = chess2::flip_bitboard(new_physical_bitboard); // Flip the bitboard to physical board perspective
                    }

                    // Show computer move
                    if !players_turn {
                        show_move(new_physical_bitboard, &piece_physical_move, &mut grid_sr, &hall_sensor, led_strobe_us, &mut delay)
                    }

                    board = new_board;
                },
                Err(error) => {                    
                    match error {
                        TurnError::Win => {

                            // Show computer move
                            if !players_turn {

                                // Get what the phsysical bitboard should be after the turn is made
                                let mut new_physical_bitboard = board.to_bitboard();
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

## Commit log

2023-03-18 Added basic move generation
    Made a function which returns a bitboard, where a bit switched to 1
    indicates that the given piece can move there. No advanced functionality
    such as en passant, double move, or castling is implemented yet.
2023-03-26 is_mate bufix
    Fixed scenario where a checkmate was not registered because a pawn had a
    valid move.
    [main.rs]
2023-03-29 Added new_turn function
    Function returns a new board if the move is valid including updated bitboards, points, etc.
2023-03-31 Added gen_best_move function
    Finds the best move on the board with a given depth. Uses minimax
    algorithms. Also made bugfixes regarding kings being able to move into
    check.
    [main.rs]
2023-03-31 Added alpha beta pruning
    Branches will now be pruned if they aren't necassary to search. Fixed
    bug in is_mate. Fixed bug in new_turn where en_passant capture would not
    give any value.
    [main.rs]
2023-03-31 More is_mate bugfixes
    Fixed is_mate not accounting for moves which can block the checking
    pieces path.
    [main.rs]
2023-04-04 Added fen_encode function
    Made a debugging function to encode the engines board representation into a fen
    string.
2023-04-05 midway through is_mate bugfix
    [main.rs]
2023-04-06 is_mate bugfix
    Fixed is_mate not accounting for moves of pieces not putting the king in
    check. This could be a problem if a friendly piece tries to capture an
    enemy piece putting the king in check, but exposes check from another
    piece.
    [main.rs]
2023-04-08 Game is playable against ai.
    Running the program now allows a player to verse the minimax algorithm.
    Bugfixed black pawns moving improperly aswell.
    [main.rs]
2023-04-09 Added pawn piece promotion
    Basic pawn promotion where they always promote to queens. Additionally
    made bugfix to castle where a king could still castle after it had moved.
    Also fixed moves bitboard not being correct for the king bits when queen and kingside could be
    castled to.
    [main.rs]
2023-04-13 Fixed bug in new_turn
    Fixed bug where team bitboards were not being updated when a capture
    happened. This caused false checkmates during a game.
    [main.rs]
2023-04-14 Bugfixed castle and is mate
    Removed unnecasary break from is mate to stop it returning early when
    checking if the king is able to move to any squares. Added condition to
    castle function that checks the rook at rook_bit actaully exists on the
    board.
    [main.rs]
2023-04-17 Overhauled is_mate function
    Rewrote the majority of is_mate to reduce bugs, and to simplify it.
    Simplifaction will allow easier bug fixing in the future.
    [main.rs]
2023-04-21 is_mate bugfix
    Fixed bug with is_mate where a square that a pawn was attacking could
    block a checking piece. The pawn couldn't actually move to this square,
    so a fix was implemented that checks if the pawn can actually move to
    the square where it is trying to block mate.
    Additionally tried to add heatmaps for piece advantageous squares. After
    implementing a new way to sort the moves in order_moves I tested it, and
    it was far slower than the old way. Just commiting for documentation.
    [main.rs]
2023-04-21 Opening heatmaps implemented
    The ai now conisders values from the opening heatmaps when making a
    move. Additionally fixed castling reseting turns_since_capture in
    new_turn.
    [main.rs]
2023-04-28 is_mate bugfix
    Added additional condition when returning false, king must not be in
    check after a move that blocks the initial check. Additionally made old
    moves in transposition table delete themselves. And gave a value for
    pawn promotion to queen. This encourages the algorithm to promote.
    [main.rs]
2023-05-01 Fixed typo affecting minimax algorithm
    Typo in the alpha beta pruning caused function to never return minimum
    values. The typo has been fixed. Additionally order_move now used a
    change in the heatmap value from the initial to the final square. So a
    piece is encouraged to hold an advantageous square.
    [main.rs]
2023-05-07 Added iterative deepening
    Best moves from lower search depths are search first. This currently
    results in a longer search time overall. I think there is a bug in the
    pruning which I will have to fix.
2023-05-09 Changed alpha beta implementation
    Currently broken
    [main.rs]
2023-05-10 fixed alpha beta pruning
    [main.rs]
2023-05-12 Added timeout best_move function
    When the master branch of best_move has been running more than the
    maximum ammount of milliseconds it is aloud to run for it returns the pv
    move from a lower search depth.
2023-05-16 first embedded commit
    Removed unnecary debugging and testing code, and completely eliminated
    the std library. Project is now setup to run the chess engine on an
    stm32f103c8t6.
2023-05-28 Added KiCad project
    KiCad project contains the design and manufacturing outputs for the
    electronic chess board.
    [BOM.csv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]
2023-05-30 file organisation
    [BOM.csv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]
2023-06-01 Tweaked via placement
    Changed the position of two vias that were conflicting with the
    silkscreen. Re-generated gerbers
    [ChessBoardKiCad-B_Cu.gbr, ChessBoardKiCad-B_Mask.gbr, ChessBoardKiCad-B_Paste.gbr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]
2023-06-07 Added hall sensor and led function
    Function allows an inddividual hall effect sensor or led on the board to
    be selected.
2023-06-14 Testing board peripherals
    Added an additional module for controlling the boards character lcd.
    Additionally tested reading from hall effect sensors, lighting leds, and
    printing to character lcd in main
2023-06-17 Added function to read halls
    Added new function to read the state of the physical board to a
    bitboard
2023-06-17 Added fusion file
    Added fusion 360 file for the chess board case
    [Case.f3d]
2023-06-21 Added counter and button modules
    Added modules to make interfacing with the internal counter and attached
    button easier.
2023-06-30 Board initialisation and input
    The game will only start after the board has been setup properly by
    placing pieces in the right position. Also added a way to read a users
    move with error checking.
    [main.rs]
2023-07-03 Playable on hardware
    The game is now playable on the physical hardware. However, there is a
    game breaking bug where the board can't detect a capture move. Because
    it can't tell where the capturing piece moved.
    [main.rs]
2023-07-04 Fixed player capturing bug
    Fixed the bug where a player couldn't capture a piece because the
    find_bitboard_move function would return an error due to a piece being
    removed from the board. Now if a player first removes and enemy piece
    and then moves their piece there they can make a capture without error.
    However there is still a bug with the computer capturing.
    [main.rs]
2023-07-05 Fixed computer captures
    Now when a computer captures the player is expected to first remove
    their captured piece from the board, and then move the computer piece.
    [main.rs]
2023-07-14 Added qol features
    Added fifty move rule back into the game. Removed the effect of the
    opening heatmap after the early/mid game has ended. Added a menu to
    adjust the minimax maximum move time, and added a way to forfiet.
    Additionally added a benchmark for elapsed clock cycles calculating an
    opening move. Currently takes ~345913092 cycles.
2023-07-19 Fixed max search menu
    Fixed max search menu opening after the player made a turn
    [main.rs]
2023-07-21 Fixed bugs
    Fixed a bug where the cycle counter (struct version not DWT) would
    frequently reset due to a u32 value being used in a multiplication
    instead of a u64. This would cause the game to freeze because the time
    would reset while the minimax algorithm is running.
    Additionally fixed the computer telling you to castle a turn after it
    actually castled.
    [main.rs]
2023-07-22 Tidied code
    Removed most compilation warnings. Additionally made it so the player
    has to press the button to end the game after a stalemate or checkmate.
    This way the game won't end instantly and the player will have time to
    read the game over message.
    [main.rs]
2023-07-26 Bug fix
    Changes from last commit broke the is_mate function in some cases.
    Changed back to previous is_mate funciton to fix bugs, and refactored
    the appropriate section in is_mate to make it easier to understand.
    Fixed other misc bugs.
    [main.rs]
2023-07-29 Updated case design files
    [Case.f3d, Case.step]
2023-08-17 Updated design files
    Improved screen cover design, and added an additional brace to the
    casing. Additionally added a manufacturing directory with dxf and stl
    files for the case.
    [Brace.dxf, Case.f3d, Case.step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]
2023-08-19 Added OpenSCAD models to design
    Added OpenSCAD models for spacers that are used for mounting the
    character lcd, and plate ontop of the PCB. These were initially intended
    to be washers, but 3D printing allows them to be one piece rather than
    multiple stacked washers. This makes assembly easier. Additionally added
    an OpenSCAD file for a chess base piece, which can be used to convert
    normal chess pieces into ones with magnets.
    [ChessPieceBase.scad, CutCylinder.scad, PlateSpacer.stl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]
2023-09-13 Bugfix
    Fixed bug where game would brick if the player starts as the black team.
    Made additional usability improvements.
    [main.rs]
